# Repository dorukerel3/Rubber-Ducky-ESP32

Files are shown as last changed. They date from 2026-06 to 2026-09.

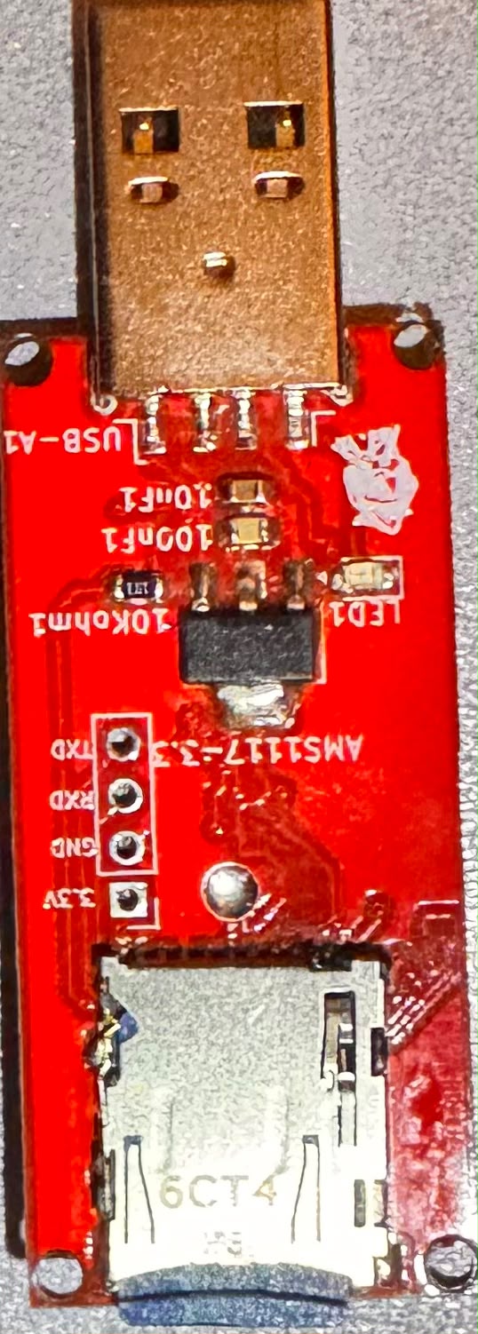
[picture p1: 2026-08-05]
images/front.jpg

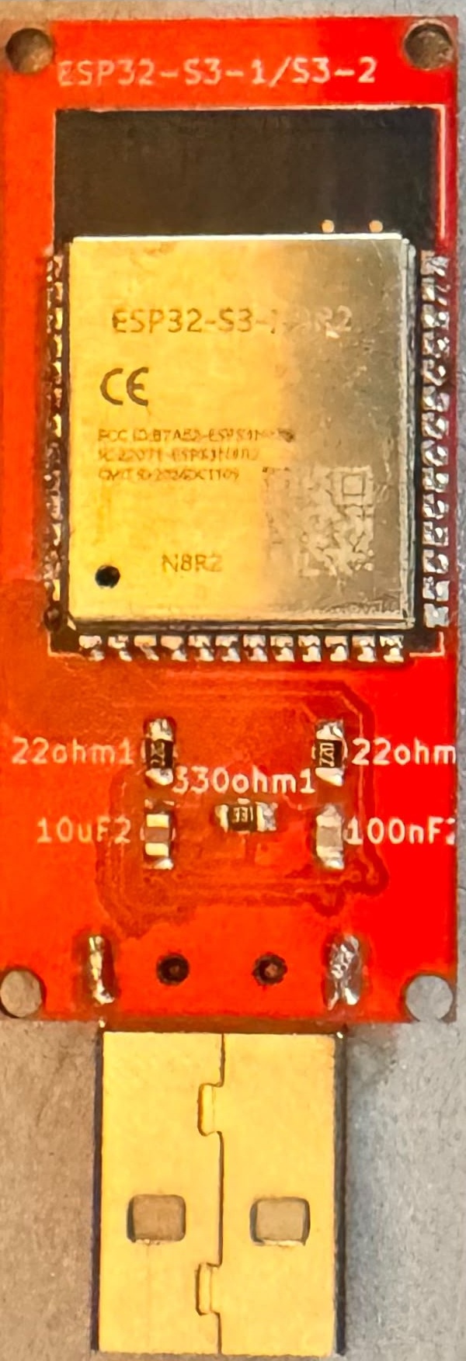
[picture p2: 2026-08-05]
images/back.jpg

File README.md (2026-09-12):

# Rubber-Ducky-ESP32 (Silicon Ghost)

Custom **ESP32-S3** HID-injection tool in a USB flash-drive form factor. Runs a DuckyScript-compatible payload interpreter directly from a MicroSD card, with keyboard + mouse injection, five keyboard layouts, sequential multi-stage execution, and a browser based OTA firmware updater, all in a single-`.ino` sketch built around a heap-fragmentation-free, industrial-grade hot path.

The firmware is engineered to reach the same effective per-keystroke throughput class as commercial injectors (Hak5 Rubber Ducky / Flipper Zero BadUSB), while still reading uncompiled `.txt` payloads from the SD card on the fly, no `.bin` pre-compilation step required.

---

## Table of Contents

- [Feature Summary](#feature-summary)
- [Hardware](#hardware)
- [Architecture Highlights](#architecture-highlights)
- [SD Card Layout](#sd-card-layout)
- [DuckyScript Command Reference](#duckyscript-command-reference)
- [Keyboard Layouts](#keyboard-layouts)
- [OTA Firmware Update](#ota-firmware-update)
- [LED Status Codes](#led-status-codes)
- [Build & Flash](#build--flash)
- [Configuration Constants](#configuration-constants)
- [Repository Contents](#repository-contents)
- [Disclaimer](#disclaimer)
- [License](#license)

---

## Feature Summary

| Capability | Detail |
|---|---|
| USB enumeration | Native composite HID (keyboard + mouse) via ESP32-S3 TinyUSB stack, no host-side driver install |
| Payload source | Uncompiled `.txt` DuckyScript files, read live from MicroSD, no pre-compilation |
| Multi-stage execution | Sequential run of every `N.txt` file in card root, sorted numerically |
| Keyboard layouts | 5 layouts: **EN, TR, FR, DE, JP**, switchable mid-payload with `LAYOUT` |
| Character resolution | **O(1)** 256-entry lookup tables per layout + tiny sorted overflow table for code points > 255 |
| I/O strategy | 512-byte chunked SD reads into a fixed RAM buffer; zero character-by-character file reads |
| Memory model | **Zero use of the Arduino `String` class**. All parsing on `char[]` buffers with `strtok_r`/`strtol`/`strchr`. No heap allocations after `setup()` |
| HID timing | `delayMicroseconds()`-based press/release intervals (default 1 ms), an order of magnitude tighter than a naive Arduino sketch |
| OTA updates | Browser based upload page over a self-hosted WiFi Access Point, gated by a boot-time trigger |
| Status feedback | single LED signaling for ready / SD error / no payload / OTA modes |

---

## Hardware

| Aspect | Part / Value |
|---|---|
| Microcontroller | **ESP32-S3-WROOM-2** (N32R8V recommended, 32 MB flash / 8 MB PSRAM) |
| Power regulation | AP2112K-3.3 (5 V USB → 3.3 V LDO) |
| USB connector | Molex 48037-2200 Type-A |
| SD connector | Hirose DM3AT-SF-PEJM5 (MicroSD, SPI mode) |
| Status LED | GPIO 46 |
| SD SPI bus | HSPI: CS 10, MOSI 11, SCK 12, MISO 13 |
| OTA trigger pin | GPIO 4 (`INPUT_PULLUP`, hold to GND at boot) |

PCB schematic and layout designed in **KiCad**. Full Gerbers, BOM/CPL, 3D models and assembly notes for independent fabrication live under `Bad_Usb_Files/`.

---

## Architecture Highlights

The firmware is written to industrial-embedded standards, not hobby Arduino conventions.

**Zero-allocation hot path.** Every text-processing routine (line reading, tokenisation, command dispatch, UTF-8 decoding) operates on stack-resident `char[]` buffers. The Arduino `String` class is not linked anywhere in the runtime, eliminating heap fragmentation entirely.

**Chunked buffered I/O.** SD payloads are read in 512-byte blocks into a `LineReader` struct that walks a pointer through the buffer, transparently stitching lines across chunk boundaries. `File::readStringUntil()` is not used.

**O(1) character lookup.** Every layout's charmap is expanded once at boot (`buildCharTables()`) into a flat 256-entry array indexed directly by Unicode code point. A single memory dereference (`g_table256[layout][cp]`) retrieves the HID report (modifier + keycode) for any Latin-1 character. Code points above 255 (TR `İığĞşŞ`, FR `œŒ`, the shared `€`) live in a per-layout overflow table of ≤ 8 entries, serviced by binary search: mathematically O(log n) on a single-digit n, effectively free.

**Microsecond HID timing.** Press/release spacing runs on `delayMicroseconds()` (default 1 ms per phase) rather than the millisecond-scale `delay()` calls a typical sketch uses. The interval sits above the standard 1 ms USB HID polling interrupt so no reports are dropped, but well below anything a human scale delay would impose, putting the effective character rate in the same class as dedicated commercial injectors.

**Fixed size stage table.** SD root discovery lands into a static `int[256]` sorted with an insertion sort. No `std::vector`, no `std::sort`, no allocator activity.

---

## SD Card Layout

Format the card as **FAT32**. The firmware only touches the root directory.

- Files are matched by exact pattern: **numeric basename + `.txt`** (case-insensitive extension).
- Between stages the interpreter waits 500 ms, resets `g_layout` to `EN`, and clears the `REPEAT` history; stages do not leak state.
- After the last stage completes the LED turns off and the device halts. It does **not** loop back and rerun stage 1 automatically.

---

## DuckyScript Command Reference

All commands are case-sensitive and one per line. Blank lines and lines beginning with `REM`, `//`, or `#` are ignored.

### Text injection

| Command | Behavior |
|---|---|
| `STRING <text>` | Type UTF-8 text through the active layout |
| `STRINGLN <text>` | Same as `STRING`, then press `ENTER` |
| `STRING_DELAY <ms> <text>` | Type text with an inter-character pause of `<ms>` milliseconds |
| `STRINGLN_DELAY <ms> <text>` | As above, then `ENTER` |

### Timing

| Command | Behavior |
|---|---|
| `DELAY <ms>` | Blocking wait for `<ms>` milliseconds |
| `DEFAULT_DELAY <ms>` / `DEFAULTDELAY <ms>` | Insert this delay after every subsequent command |

### Modifier / key combos

Combine any of `CTRL`/`CONTROL`, `SHIFT`, `ALT`, `GUI`/`WINDOWS`/`COMMAND`/`META`, `ALTGR`/`RALT` with one named key or single character.

### Named keys

`ENTER`/`RETURN`, `TAB`, `SPACE`, `BACKSPACE`/`BKSP`, `DELETE`/`DEL`, `ESCAPE`/`ESC`, `HOME`, `END`, `INSERT`, `PAGEUP`/`PAGE_UP`, `PAGEDOWN`/`PAGE_DOWN`, `UP`/`DOWN`/`LEFT`/`RIGHT`, `CAPSLOCK`/`CAPS_LOCK`, `NUMLOCK`/`NUM_LOCK`, `SCROLLLOCK`/`SCROLL_LOCK`, `PRINTSCREEN`/`PRTSC`, `PAUSE`/`BREAK`, `MENU`/`APP`, `F1` through `F24`.

### Mouse

| Command | Behavior |
|---|---|
| `MOUSE_MOVE <dx> <dy>` | Relative move; any range, auto-chunked into ±127 HID reports |
| `MOUSE_CLICK LEFT\|RIGHT\|MIDDLE` | Single click |
| `MOUSE_PRESS LEFT\|RIGHT\|MIDDLE` | Hold button down (no auto-release) |
| `MOUSE_RELEASE` | Release all mouse buttons |
| `MOUSE_SCROLL <n>` | Vertical wheel scroll, `-127..127` |

### Control flow

| Command | Behavior |
|---|---|
| `REPEAT <n>` | Run the previous non-`REPEAT` line `<n>` times |
| `LAYOUT <code>` | Switch active keyboard layout: `EN`, `TR`, `FR`, `DE`, `JP` |

---

## Keyboard Layouts

Layouts are compile-time embedded and activated at runtime with `LAYOUT`.

| Code | Coverage |
|---|---|
| `EN` | US ANSI. No remapping, all ASCII passes straight through to the HID report. |
| `TR` | Turkish-Q. Full charmap for `ı İ ğ Ğ ş Ş ö Ö ü Ü ç Ç`, all AltGr-shifted symbols, and `€`. |
| `FR` | French AZERTY with dead-key composition for accented vowels, plus `œ Œ` and `€`. |
| `DE` | German QWERTZ. `ä Ä ö Ö ü Ü ß` and `€`, with a small selection of dead-key composed accents. |
| `JP` | JIS punctuation charmap for a host configured with the Japanese JIS layout. Full kana input is not supported. |

At the start of each stage `g_layout` resets to `EN`.

---

## OTA Firmware Update

The firmware ships with a browser-based OTA updater that runs on a self-hosted WiFi Access Point. It is **off by default** and cannot be reached from the target machine or the surrounding network under normal operation.

### Trigger

Two independent triggers, either alone is enough:

1. **SD card file**:  drop an empty file named `OTA.TXT` in the SD root and reset the board. The firmware detects the file, deletes it immediately, and enters OTA mode.
2. **Hardware pin**:  hold `GPIO 4` to `GND` while the board powers on / resets.

If neither trigger is present, no radio is initialised, no AP is broadcast, and the OTA code path never runs. HID timing is completely unaffected.

### Using it

1. Trigger OTA mode. LED begins a slow **double-blink**.
2. Join the WiFi network **`BadUSB-OTA`** with `OTA_AP_PASSWORD`.
3. Browse to **`http://192.168.4.1/`**.
4. The browser prompts a Basic-Auth login: username `admin`, password `OTA_UPLOAD_PASSWORD`.
5. Pick a compiled `.bin` and click **Upload**.
6. On success the board auto-reboots. On failure it reboots back into the previous firmware. A bad or interrupted upload cannot brick the device.
7. If no upload occurs within **3 minutes**, OTA mode times out and boots normally.

### Security notes

- Both passwords **must** be set to real values before flashing; the shipped file uses `CHANGE_ME_*` placeholders on purpose.
- `OTA_AP_PASSWORD` must be at least **8 characters** or `WiFi.softAP()` will silently create an *open* network.
- Basic Auth over the AP is clear-text on the RF side. Treat OTA mode as a physical-access convenience, not a hardened remote-update channel.

---

## LED Status Codes

| Pattern | Meaning |
|---|---|
| Solid ON | Normal boot succeeded; running payloads |
| Solid OFF (after run) | All payload stages completed; device halted |
| Fast blink 100 ms on / 100 ms off | SD card failed to mount |
| Slow blink 500 ms on / 500 ms off | No `N.txt` payload files found, or a payload file failed to open |
| Slow double-blink (OTA mode) | AP broadcasting, waiting for upload |
| Solid ON / rapid flicker (OTA mode) | Firmware upload in progress |

---

## Build & Flash

**Board target:** ESP32-S3 (`Tools → Board → ESP32 Arduino → ESP32S3 Dev Module`).

| Setting | Value |
|---|---|
| USB CDC On Boot | Enabled |
| USB Mode | `USB-OTG (TinyUSB)` |
| USB Firmware MSC On Boot | Disabled |
| USB DFU On Boot | Disabled |
| Partition Scheme | `Default 4MB with spiffs` (or `Huge APP` for 32 MB N32R8V) |
| Flash Size | Match module (16 MB / 32 MB) |

Libraries: `USB`, `USBHIDKeyboard`, `USBHIDMouse`, `SD`, `SPI`, `WiFi`, `WebServer`, `Update` all ship with the ESP32 Arduino core; no external installs required.

### First flash

1. Open `Bad_Usb_Files/BadUSB_Optimized.ino`.
2. Change the four `CHANGE_ME_*` placeholders near the top of the file.
3. Connect the board over USB, select its serial port, hit **Upload**.
4. Copy your `N.txt` payloads onto a FAT32-formatted MicroSD card and insert it. Power cycle.

### Subsequent updates

Either reflash over USB, or use the OTA flow: **Sketch → Export Compiled Binary**, drop `OTA.TXT` on the card, reboot, upload the `.bin` at `http://192.168.4.1/`.

---

## Configuration Constants

| Constant | Purpose | Default |
|---|---|---|
| `PIN_SD_CS`, `PIN_SD_MOSI`, `PIN_SD_SCK`, `PIN_SD_MISO` | SD SPI wiring | 10 / 11 / 12 / 13 |
| `PIN_LED` | Status LED | 46 |
| `PIN_OTA_TRIGGER` | OTA trigger pin (LOW at boot = enter OTA) | 4 |
| `KEY_PRESS_US`, `KEY_RELEASE_US` | HID press / release intervals | 1000 µs each |
| `CHUNK_SIZE`, `DUCKY_LINE_MAX` | SD read chunk + max line length | 512 / 512 bytes |
| `MAX_STAGES` | Cap on `N.txt` payload files scanned | 256 |
| `OTA_AP_SSID` | Broadcast AP name in OTA mode | `BadUSB-OTA` |
| `OTA_AP_PASSWORD` | WPA2 password for the AP (≥ 8 chars) | placeholder |
| `OTA_UPLOAD_USERNAME` / `OTA_UPLOAD_PASSWORD` | Basic Auth for the upload page | `admin` / placeholder |
| `OTA_TRIGGER_FILE` | SD filename that triggers OTA on boot | `/OTA.TXT` |
| `OTA_IDLE_TIMEOUT_MS` | OTA mode auto-exit after this much no-activity | 180 000 (3 min) |

> **Note:** the internal line-buffer constant is named `DUCKY_LINE_MAX` (not `LINE_MAX`) to avoid a preprocessor collision with the POSIX `LINE_MAX` macro pulled in transitively by `Arduino.h → FreeRTOS → limits.h` on the Xtensa toolchain.

---

## Repository Contents

```
/
├── Bad_Usb_Files/           ← firmware source, PCB Gerbers, BOM/CPL, 3D models
│   └── BadUSB_Optimized.ino
├── images/                  ← hardware photos and diagrams
├── LICENSE                  ← MIT
└── README.md                ← this file
```

---

## Disclaimer

This project is developed strictly for **educational purposes and authorized security research**. It is **not intended for use on systems, networks, or hardware without the explicit consent of the owner**. The author accepts no responsibility for misuse. Local law regarding possession and use of HID-injection tooling varies; verify your jurisdiction before building or carrying the device.

---

## License

MIT. See [`LICENSE`](LICENSE).

**Author:** Doruk Erel

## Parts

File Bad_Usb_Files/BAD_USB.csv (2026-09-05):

Id | Designator | Footprint | Quantity | Designation | Supplier and ref
1 | 10Kohm1 | R_0805_2012Metric_Pad1.20x1.40mm_HandSolder | 1 | 10K
2 | 10uF1, 10uF2 | C_0805_2012Metric_Pad1.18x1.45mm_HandSolder | 2 | 10uF
3 | 22ohm1, 22ohm2 | R_0805_2012Metric_Pad1.20x1.40mm_HandSolder | 2 | 22
4 | 100nF1, 100nF2 | C_0805_2012Metric_Pad1.18x1.45mm_HandSolder | 2 | 100nF
5 | 330ohm1 | R_0805_2012Metric_Pad1.20x1.40mm_HandSolder | 1 | 330
6 | AP2112K | SOT-23-5 | 1 | AP2112K-3.3
7 | ESP32-S3-1/S3-2 | ESP32-S3-WROOM-1 | 1 | ESP32-S3-WROOM-1/ESP32-S3-WROOM-2
8 | J1 | microSD_HC_Hirose_DM3AT-SF-PEJM5 | 1 | Conn_01x04
9 | LED1 | LED_0805_2012Metric_Pad1.15x1.40mm_HandSolder | 1 | LED
10 | USB-A1 | USB_A_Molex_48037-2200_Horizontal | 1 | USB_A

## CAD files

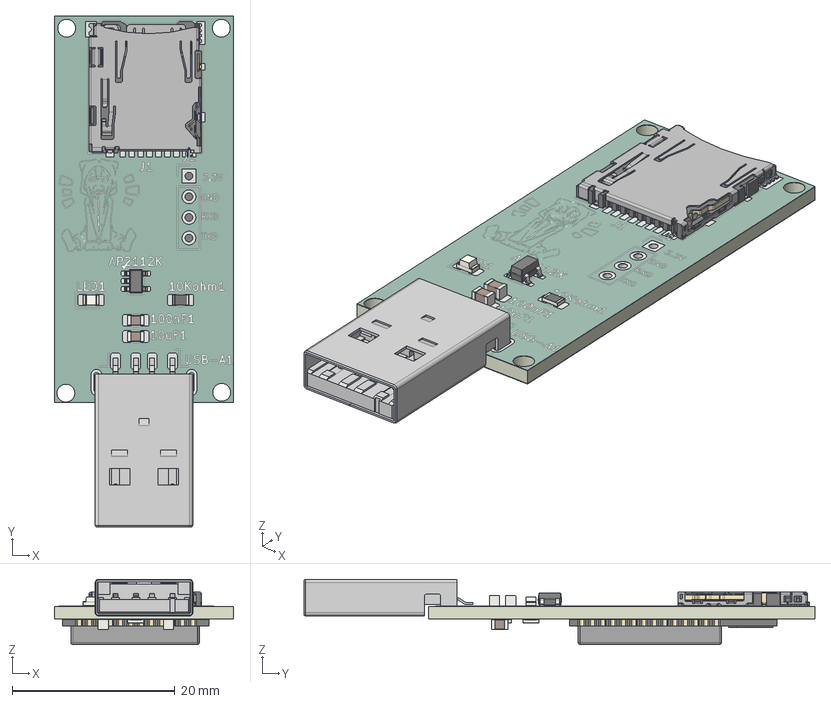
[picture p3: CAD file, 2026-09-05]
Bad_Usb_Files/Bad_Usb_Design.STEP
22.0 x 62.8 x 8.03 mm
C_0805_2012Metric x 4
microSD_HC_Hirose_DM3AT-SF-PEJM5
SOT-23-5
LED_0805_2012Metric
R_0805_2012Metric x 4
ESP32-S3-WROOM-1
BAD_USB_copper
BAD_USB_pad
BAD_USB_via
BAD_USB_silkscreen
BAD_USB_silkscreen_1
BAD_USB_soldermask
BAD_USB_soldermask_1
BAD_USB_PCB

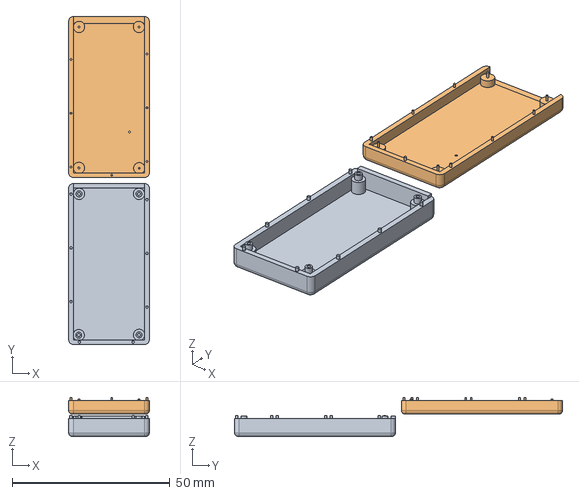
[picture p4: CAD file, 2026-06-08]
Bad_Usb_Files/Bad_Usb_Enclosure.step
25.6 x 104.1 x 12.4 mm

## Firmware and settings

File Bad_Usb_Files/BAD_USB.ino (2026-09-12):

#include "USB.h"
#include "USBHIDKeyboard.h"
#include "USBHIDMouse.h"
#include <SPI.h>
#include <SD.h>
#include <WiFi.h>
#include <ArduinoOTA.h>
#include <cstring>
#include <cstdlib>
#include <cctype>

static constexpr uint8_t PIN_SD_CS   = 10;
static constexpr uint8_t PIN_SD_MOSI = 11;
static constexpr uint8_t PIN_SD_SCK  = 12;
static constexpr uint8_t PIN_SD_MISO = 13;
static constexpr uint8_t PIN_LED     = 46;
static constexpr uint8_t PIN_OTA_TRIGGER = 4;

static const char*      OTA_AP_SSID            = "BadUSB-OTA";
static const char*      OTA_AP_PASSWORD        = "CHANGE_ME_AP_PW";
static const char*      OTA_HOSTNAME           = "badusb-esp32";
static const char*      OTA_UPLOAD_PASSWORD    = "CHANGE_ME_UPLOAD_PW";
static const char*      OTA_TRIGGER_FILE       = "/OTA.TXT";
static constexpr uint32_t OTA_IDLE_TIMEOUT_MS  = 180000;

static constexpr uint32_t KEY_PRESS_US   = 1000;
static constexpr uint32_t KEY_RELEASE_US = 1000;

static constexpr uint8_t MOD_NONE  = 0x00;
static constexpr uint8_t MOD_CTRL  = 0x01;
static constexpr uint8_t MOD_SHIFT = 0x02;
static constexpr uint8_t MOD_ALT   = 0x04;
static constexpr uint8_t MOD_GUI   = 0x08;
static constexpr uint8_t MOD_RALT  = 0x10;

#ifndef KEY_PRINT_SCREEN
#  define KEY_PRINT_SCREEN  0xCE
#endif
#ifndef KEY_SCROLL_LOCK
#  define KEY_SCROLL_LOCK   0xCF
#endif
#ifndef KEY_PAUSE
#  define KEY_PAUSE         0xD0
#endif
#ifndef KEY_NUM_LOCK
#  define KEY_NUM_LOCK      0xDB
#endif
#ifndef KEY_MENU
#  define KEY_MENU          0xED
#endif
#ifndef KEY_F13
#  define KEY_F13  0xF0
#  define KEY_F14  0xF1
#  define KEY_F15  0xF2
#  define KEY_F16  0xF3
#  define KEY_F17  0xF4
#  define KEY_F18  0xF5
#  define KEY_F19  0xF6
#  define KEY_F20  0xF7
#  define KEY_F21  0xF8
#  define KEY_F22  0xF9
#  define KEY_F23  0xFA
#  define KEY_F24  0xFB
#endif

struct CharDef {
    uint32_t cp;
    uint8_t  k1;
    uint8_t  k2;
    bool     ralt;
};

static const CharDef EN_DEFS[] = {};

static const CharDef JP_DEFS[] = {
    {0x0022, '@',  0, false},
    {0x0026, '^',  0, false},
    {0x0027, '&',  0, false},
    {0x0028, '*',  0, false},
    {0x0029, '(',  0, false},
    {0x002A, '"',  0, false},
    {0x002B, ':',  0, false},
    {0x003A, '\'', 0, false},
    {0x003D, '_',  0, false},
    {0x005B, ']',  0, false},
    {0x005D, '\\', 0, false},
    {0x005E, '=',  0, false},
    {0x0060, '{',  0, false},
    {0x007B, '}',  0, false},
    {0x007D, '|',  0, false},
    {0x007E, '+',  0, false},
    {0x0040, '[',  0, false},
};

static const CharDef TR_DEFS[] = {
    {0x0069, (uint8_t)0x27, 0,   false},
    {0x0130, (uint8_t)0x22, 0,   false},
    {0x0131, 'i',  0,   false},
    {0x011F, '[',  0,   false},
    {0x011E, '{',  0,   false},
    {0x00FC, ']',  0,   false},
    {0x00DC, '}',  0,   false},
    {0x015F, ';',  0,   false},
    {0x015E, ':',  0,   false},
    {0x00F6, ',',  0,   false},
    {0x00D6, '<',  0,   false},
    {0x00E7, '.',  0,   false},
    {0x00C7, '>',  0,   false},
    {0x002E, '/',  0,   false},
    {0x003A, '?',  0,   false},
    {0x0027, '@',  0,   false},
    {0x005E, '#',  0,   false},
    {0x002B, '$',  0,   false},
    {0x0026, '^',  0,   false},
    {0x002F, '&',  0,   false},
    {0x0028, '*',  0,   false},
    {0x0029, '(',  0,   false},
    {0x003D, ')',  0,   false},
    {0x002A, '-',  0,   false},
    {0x003F, '_',  0,   false},
    {0x002D, '=',  0,   false},
    {0x005F, '+',  0,   false},
    {0x0040, 'q',  0,   true },
    {0x0023, '3',  0,   true },
    {0x0024, '4',  0,   true },
    {0x005B, '8',  0,   true },
    {0x005D, '9',  0,   true },
    {0x007B, '7',  0,   true },
    {0x007D, '0',  0,   true },
    {0x007E, ']',  0,   true },
    {0x005C, '-',  0,   true },
    {0x007C, '_',  0,   true },
    {0x003C, ',',  0,   true },
    {0x003E, '.',  0,   true },
    {0x20AC, 'e',  0,   true },
};

static const CharDef FR_DEFS[] = {
    {0x00E9, '\'', 'e', false},
    {0x00C9, '\'', 'E', false},
    {0x00E1, '\'', 'a', false},
    {0x00C1, '\'', 'A', false},
    {0x00FA, '\'', 'u', false},
    {0x00DA, '\'', 'U', false},
    {0x00F3, '\'', 'o', false},
    {0x00D3, '\'', 'O', false},
    {0x00ED, '\'', 'i', false},
    {0x00CD, '\'', 'I', false},
    {0x00E8, '`',  'e', false},
    {0x00C8, '`',  'E', false},
    {0x00E0, '`',  'a', false},
    {0x00C0, '`',  'A', false},
    {0x00F9, '`',  'u', false},
    {0x00D9, '`',  'U', false},
    {0x00E2, '^',  'a', false},
    {0x00C2, '^',  'A', false},
    {0x00EA, '^',  'e', false},
    {0x00CA, '^',  'E', false},
    {0x00EE, '^',  'i', false},
    {0x00CE, '^',  'I', false},
    {0x00F4, '^',  'o', false},
    {0x00D4, '^',  'O', false},
    {0x00FB, '^',  'u', false},
    {0x00DB, '^',  'U', false},
    {0x00E4, '"',  'a', false},
    {0x00C4, '"',  'A', false},
    {0x00EB, '"',  'e', false},
    {0x00CB, '"',  'E', false},
    {0x00EF, '"',  'i', false},
    {0x00CF, '"',  'I', false},
    {0x00F6, '"',  'o', false},
    {0x00D6, '"',  'O', false},
    {0x00FC, '"',  'u', false},
    {0x00DC, '"',  'U', false},
    {0x00E7, ',',  0,   true },
    {0x00C7, '<',  0,   true },
    {0x0153, 'q',  0,   true },
    {0x0152, 'Q',  0,   true },
    {0x20AC, 'e',  0,   true },
    {0x00F1, '~',  'n', false},
    {0x00D1, '~',  'N', false},
    {0x00E3, '~',  'a', false},
    {0x00C3, '~',  'A', false},
    {0x00F5, '~',  'o', false},
    {0x00D5, '~',  'O', false},
};

static const CharDef DE_DEFS[] = {
    {0x00E4, 'a',  0,   true },
    {0x00C4, 'A',  0,   true },
    {0x00F6, 'o',  0,   true },
    {0x00D6, 'O',  0,   true },
    {0x00FC, 'u',  0,   true },
    {0x00DC, 'U',  0,   true },
    {0x00DF, 's',  0,   true },
    {0x20AC, 'e',  0,   true },
    {0x00E9, '\'', 'e', false},
    {0x00E0, '`',  'a', false},
};

enum LayoutID : uint8_t { LAY_EN = 0, LAY_TR, LAY_FR, LAY_DE, LAY_JP, LAYOUT_COUNT };

struct LayoutDefSet {
    const char*    name;
    const CharDef* defs;
    uint16_t       len;
};

static const LayoutDefSet LAYOUT_DEFS[LAYOUT_COUNT] = {
    { "EN", EN_DEFS, (uint16_t)(sizeof(EN_DEFS) / sizeof(CharDef)) },
    { "TR", TR_DEFS, (uint16_t)(sizeof(TR_DEFS) / sizeof(CharDef)) },
    { "FR", FR_DEFS, (uint16_t)(sizeof(FR_DEFS) / sizeof(CharDef)) },
    { "DE", DE_DEFS, (uint16_t)(sizeof(DE_DEFS) / sizeof(CharDef)) },
    { "JP", JP_DEFS, (uint16_t)(sizeof(JP_DEFS) / sizeof(CharDef)) },
};

struct CharEntry {
    bool    mapped = false;
    bool    ralt   = false;
    uint8_t k1     = 0;
    uint8_t k2     = 0;
};

struct ExtEntry {
    uint32_t  cp;
    CharEntry entry;
};

static constexpr uint8_t MAX_EXT_PER_LAYOUT = 8;

static CharEntry g_table256[LAYOUT_COUNT][256];
static ExtEntry  g_ext[LAYOUT_COUNT][MAX_EXT_PER_LAYOUT];
static uint8_t   g_extCount[LAYOUT_COUNT] = {0};

static void buildCharTables() {
    for (uint8_t L = 0; L < LAYOUT_COUNT; L++) {
        g_extCount[L] = 0;
        const CharDef* defs = LAYOUT_DEFS[L].defs;
        const uint16_t n    = LAYOUT_DEFS[L].len;
        for (uint16_t i = 0; i < n; i++) {
            const CharDef& d = defs[i];
            CharEntry e;
            e.mapped = true;
            e.ralt   = d.ralt;
            e.k1     = d.k1;
            e.k2     = d.k2;
            if (d.cp < 256) {
                g_table256[L][d.cp] = e;
            } else if (g_extCount[L] < MAX_EXT_PER_LAYOUT) {
                g_ext[L][g_extCount[L]++] = { d.cp, e };
            }
        }
        for (uint8_t i = 1; i < g_extCount[L]; i++) {
            ExtEntry key = g_ext[L][i];
            int j = (int)i - 1;
            while (j >= 0 && g_ext[L][j].cp > key.cp) {
                g_ext[L][j + 1] = g_ext[L][j];
                j--;
            }
            g_ext[L][j + 1] = key;
        }
    }
}

static inline bool lookupChar(uint8_t layout, uint32_t cp, CharEntry* out) {
    if (cp < 256) {
        *out = g_table256[layout][cp];
        return out->mapped;
    }
    const uint8_t   n   = g_extCount[layout];
    const ExtEntry* arr = g_ext[layout];
    int lo = 0, hi = (int)n - 1;
    while (lo <= hi) {
        const int mid = (lo + hi) >> 1;
        if (arr[mid].cp == cp) { *out = arr[mid].entry; return true; }
        if (arr[mid].cp < cp)  lo = mid + 1; else hi = mid - 1;
    }
    return false;
}

static uint8_t g_layout = LAY_EN;

static USBHIDKeyboard Keyboard;
static USBHIDMouse    Mouse;
static SPIClass       sdSPI(HSPI);

static uint16_t g_defaultDelay = 0;

static void blinkHalt(uint16_t onMs, uint16_t offMs) {
    for (;;) {
        digitalWrite(PIN_LED, HIGH); delay(onMs);
        digitalWrite(PIN_LED, LOW);  delay(offMs);
    }
}

static volatile bool g_otaActivity = false;

static void runOtaMode() {
    WiFi.mode(WIFI_AP);
    WiFi.softAP(OTA_AP_SSID, OTA_AP_PASSWORD);

    ArduinoOTA.setHostname(OTA_HOSTNAME);
    ArduinoOTA.setPassword(OTA_UPLOAD_PASSWORD);

    ArduinoOTA.onStart([]() {
        g_otaActivity = true;
        digitalWrite(PIN_LED, HIGH);
    });
    ArduinoOTA.onEnd([]() {
        digitalWrite(PIN_LED, LOW);
    });
    ArduinoOTA.onProgress([](unsigned int progress, unsigned int total) {
        g_otaActivity = true;
        digitalWrite(PIN_LED, (progress / 4096) % 2);
    });
    ArduinoOTA.onError([](ota_error_t error) {
        digitalWrite(PIN_LED, LOW);
    });

    ArduinoOTA.begin();

    uint32_t lastBlink    = millis();
    uint32_t lastActivity = millis();
    bool     ledState     = false;
    for (;;) {
        ArduinoOTA.handle();
        if (g_otaActivity) {
            g_otaActivity = false;
            lastActivity  = millis();
        }
        if (millis() - lastBlink > 500) {
            lastBlink = millis();
            ledState  = !ledState;
            digitalWrite(PIN_LED, ledState);
        }
        if (millis() - lastActivity > OTA_IDLE_TIMEOUT_MS) {
            ArduinoOTA.end();
            WiFi.softAPdisconnect(true);
            WiFi.mode(WIFI_OFF);
            digitalWrite(PIN_LED, LOW);
            return;
        }
    }
}

static constexpr size_t CHUNK_SIZE = 512;
static constexpr size_t DUCKY_LINE_MAX   = 512;

struct LineReader {
    File   file;
    char   buf[CHUNK_SIZE];
    size_t len = 0;
    size_t pos = 0;
    bool   eof = false;

    void begin(File f) {
        file = f;
        len = 0; pos = 0; eof = false;
    }

    bool refill() {
        if (eof) return false;
        int n = file.read((uint8_t*)buf, CHUNK_SIZE);
        if (n <= 0) { eof = true; len = 0; pos = 0; return false; }
        len = (size_t)n;
        pos = 0;
        return true;
    }

    bool readLine(char* out, size_t outCap) {
        size_t outLen = 0;
        for (;;) {
            if (pos >= len) {
                if (!refill()) {
                    if (outLen > 0) { out[outLen] = '\0'; return true; }
                    return false;
                }
            }
            while (pos < len) {
                const char c = buf[pos++];
                if (c == '\n') {
                    if (outLen > 0 && out[outLen - 1] == '\r') outLen--;
                    out[outLen] = '\0';
                    return true;
                }
                if (outLen < outCap - 1) out[outLen++] = c;
            }
        }
    }
};

static char* trimInPlace(char* s) {
    while (*s == ' ' || *s == '\t') s++;
    if (*s == '\0') return s;
    char* end = s + strlen(s) - 1;
    while (end > s && (*end == ' ' || *end == '\t' || *end == '\r')) *end-- = '\0';
    return s;
}

static uint32_t utf8Next(const char** pp) {
    const uint8_t* p = (const uint8_t*)*pp;
    if (*p == 0) return 0;
    const uint8_t b0 = *p++;
    uint32_t cp;
    if (b0 < 0x80) {
        cp = b0;
    } else if ((b0 & 0xE0) == 0xC0 && p[0]) {
        cp = ((uint32_t)(b0 & 0x1F) << 6) | (p[0] & 0x3F);
        p += 1;
    } else if ((b0 & 0xF0) == 0xE0 && p[0] && p[1]) {
        cp = ((uint32_t)(b0 & 0x0F) << 12) | ((uint32_t)(p[0] & 0x3F) << 6) | (p[1] & 0x3F);
        p += 2;
    } else if ((b0 & 0xF8) == 0xF0 && p[0] && p[1] && p[2]) {
        cp = ((uint32_t)(b0 & 0x07) << 18) | ((uint32_t)(p[0] & 0x3F) << 12) |
             ((uint32_t)(p[1] & 0x3F) << 6) | (p[2] & 0x3F);
        p += 3;
    } else {
        cp = 0xFFFD;
    }
    *pp = (const char*)p;
    return cp;
}

static inline void pressKeys(uint8_t mods, uint8_t k1, uint8_t k2 = 0) {
    if (mods & MOD_CTRL)  Keyboard.press(KEY_LEFT_CTRL);
    if (mods & MOD_SHIFT) Keyboard.press(KEY_LEFT_SHIFT);
    if (mods & MOD_ALT)   Keyboard.press(KEY_LEFT_ALT);
    if (mods & MOD_GUI)   Keyboard.press(KEY_LEFT_GUI);
    if (mods & MOD_RALT)  Keyboard.press(KEY_RIGHT_ALT);
    if (k1) Keyboard.press(k1);
    delayMicroseconds(KEY_PRESS_US);
    Keyboard.releaseAll();
    delayMicroseconds(KEY_RELEASE_US);
    if (k2) {
        Keyboard.press(k2);
        delayMicroseconds(KEY_PRESS_US);
        Keyboard.release(k2);
        delayMicroseconds(KEY_RELEASE_US);
    }
}

static inline void pressCombo(uint8_t mods, uint8_t key) {
    pressKeys(mods, key);
}

static void typeCodepoint(uint32_t cp) {
    CharEntry e;
    if (lookupChar(g_layout, cp, &e)) {
        pressKeys(e.ralt ? MOD_RALT : MOD_NONE, e.k1, e.k2);
        return;
    }
    if (cp >= 0x20 && cp < 0x80) {
        pressKeys(MOD_NONE, (uint8_t)cp);
    }
}

static void cmdString(const char* text, bool appendEnter, uint32_t charDelayUs = 0) {
    const char* p = text;
    for (;;) {
        const uint32_t cp = utf8Next(&p);
        if (cp == 0) break;
        typeCodepoint(cp);
        if (charDelayUs > 0) delayMicroseconds(charDelayUs);
    }
    if (appendEnter) pressCombo(MOD_NONE, KEY_RETURN);
}

static uint8_t tokenToMod(const char* tok) {
    if (!strcmp(tok, "CTRL") || !strcmp(tok, "CONTROL"))                     return MOD_CTRL;
    if (!strcmp(tok, "SHIFT"))                                               return MOD_SHIFT;
    if (!strcmp(tok, "ALT"))                                                 return MOD_ALT;
    if (!strcmp(tok, "GUI") || !strcmp(tok, "WINDOWS") ||
        !strcmp(tok, "COMMAND") || !strcmp(tok, "META"))                     return MOD_GUI;
    if (!strcmp(tok, "ALTGR") || !strcmp(tok, "RALT"))                       return MOD_RALT;
    return MOD_NONE;
}

static uint8_t tokenToKey(const char* tok) {
    if (!strcmp(tok, "ENTER")  || !strcmp(tok, "RETURN"))      return KEY_RETURN;
    if (!strcmp(tok, "TAB"))                                   return KEY_TAB;
    if (!strcmp(tok, "SPACE"))                                 return ' ';
    if (!strcmp(tok, "BACKSPACE") || !strcmp(tok, "BKSP"))     return KEY_BACKSPACE;
    if (!strcmp(tok, "DELETE")    || !strcmp(tok, "DEL"))      return KEY_DELETE;
    if (!strcmp(tok, "ESCAPE")    || !strcmp(tok, "ESC"))      return KEY_ESC;
    if (!strcmp(tok, "HOME"))                                  return KEY_HOME;
    if (!strcmp(tok, "END"))                                   return KEY_END;
    if (!strcmp(tok, "INSERT"))                                return KEY_INSERT;
    if (!strcmp(tok, "PAGEUP")   || !strcmp(tok, "PAGE_UP"))   return KEY_PAGE_UP;
    if (!strcmp(tok, "PAGEDOWN") || !strcmp(tok, "PAGE_DOWN")) return KEY_PAGE_DOWN;
    if (!strcmp(tok, "UP"))                                    return KEY_UP_ARROW;
    if (!strcmp(tok, "DOWN"))                                  return KEY_DOWN_ARROW;
    if (!strcmp(tok, "LEFT"))                                  return KEY_LEFT_ARROW;
    if (!strcmp(tok, "RIGHT"))                                 return KEY_RIGHT_ARROW;
    if (!strcmp(tok, "CAPSLOCK")    || !strcmp(tok, "CAPS_LOCK"))    return KEY_CAPS_LOCK;
    if (!strcmp(tok, "NUMLOCK")     || !strcmp(tok, "NUM_LOCK"))     return KEY_NUM_LOCK;
    if (!strcmp(tok, "SCROLLLOCK")  || !strcmp(tok, "SCROLL_LOCK"))  return KEY_SCROLL_LOCK;
    if (!strcmp(tok, "PRINTSCREEN") || !strcmp(tok, "PRTSC"))        return KEY_PRINT_SCREEN;
    if (!strcmp(tok, "PAUSE") || !strcmp(tok, "BREAK"))        return KEY_PAUSE;
    if (!strcmp(tok, "MENU")  || !strcmp(tok, "APP"))          return KEY_MENU;
    if (!strcmp(tok, "F1"))  return KEY_F1;   if (!strcmp(tok, "F2"))  return KEY_F2;
    if (!strcmp(tok, "F3"))  return KEY_F3;   if (!strcmp(tok, "F4"))  return KEY_F4;
    if (!strcmp(tok, "F5"))  return KEY_F5;   if (!strcmp(tok, "F6"))  return KEY_F6;
    if (!strcmp(tok, "F7"))  return KEY_F7;   if (!strcmp(tok, "F8"))  return KEY_F8;
    if (!strcmp(tok, "F9"))  return KEY_F9;   if (!strcmp(tok, "F10")) return KEY_F10;
    if (!strcmp(tok, "F11")) return KEY_F11;  if (!strcmp(tok, "F12")) return KEY_F12;
    if (!strcmp(tok, "F13")) return KEY_F13;  if (!strcmp(tok, "F14")) return KEY_F14;
    if (!strcmp(tok, "F15")) return KEY_F15;  if (!strcmp(tok, "F16")) return KEY_F16;
    if (!strcmp(tok, "F17")) return KEY_F17;  if (!strcmp(tok, "F18")) return KEY_F18;
    if (!strcmp(tok, "F19")) return KEY_F19;  if (!strcmp(tok, "F20")) return KEY_F20;
    if (!strcmp(tok, "F21")) return KEY_F21;  if (!strcmp(tok, "F22")) return KEY_F22;
    if (!strcmp(tok, "F23")) return KEY_F23;  if (!strcmp(tok, "F24")) return KEY_F24;
    if (strlen(tok) == 1) return (uint8_t)tok[0];
    return 0;
}

static uint8_t mouseMask(const char* name) {
    if (!strcmp(name, "LEFT"))   return MOUSE_LEFT;
    if (!strcmp(name, "RIGHT"))  return MOUSE_RIGHT;
    if (!strcmp(name, "MIDDLE")) return MOUSE_MIDDLE;
    return 0;
}

static inline const char* skipSpaces(const char* p) {
    while (*p == ' ') p++;
    return p;
}

static char g_lastLine[DUCKY_LINE_MAX];
static bool g_hasLastLine = false;
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
void loop() {
    discoverStages();
    if (g_stageCount == 0) blinkHalt(500, 500);

    static LineReader reader;
    static char lineBuf[DUCKY_LINE_MAX];
    char path[32];

    for (int i = 0; i < g_stageCount; i++) {
        g_layout       = LAY_EN;
        g_hasLastLine  = false;

        snprintf(path, sizeof(path), "/%d.txt", g_stages[i]);
        File f = SD.open(path, FILE_READ);
        if (!f) blinkHalt(500, 500);

        reader.begin(f);
        while (reader.readLine(lineBuf, DUCKY_LINE_MAX)) {
            char* line = trimInPlace(lineBuf);
            if (*line == '\0') continue;
            executeLine(line);
            if (g_defaultDelay) delay(g_defaultDelay);
        }

        f.close();

        if (i < g_stageCount - 1) delay(500);
    }

    digitalWrite(PIN_LED, LOW);
    while (true) { delay(1000); }
}

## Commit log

2026-05-05 Gerber, BOM and POS files aded
    [BAD_USB.csv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]
2026-05-06 Gerber, Bom and Drill files
    [BAD_USB.csv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]
2026-05-07 Gerber, Bom, Drill files
    [BAD_USB.csv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]
2026-05-23 BAD USB ESP32 working code
2026-06-07 Gerber and drill files
2026-06-08 Gerber and Drill
2026-06-08 BOM and POS
    [BAD_USB.csv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]
2026-06-08 A simple enclosure for the bad usb
    [Bad_Usb_Enclosure.step]
2026-09-12 Update print statement from 'Hello' to 'Goodbye'
2026-09-12 Revise README for improved feature descriptions
    Updated the README to enhance clarity and detail on the device's features, architecture, and usage instructions.
